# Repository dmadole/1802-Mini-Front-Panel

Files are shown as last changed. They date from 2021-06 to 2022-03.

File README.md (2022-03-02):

# 1802-Mini-Front-Panel
This is the front panel card for the [1802/Mini](https://github.com/dmadole/1802-Mini) system. It supports the following features:

* Supports two, four, or six TIL311 hexadecimal displays
* Left sockets selectable for either LSB or MSB of address
* Toggle switch input to load memory with CDP1802 processor
* Displays and toggle input fully decoded on I/O port 4
* Can separately disable display or toggle I/O ability
* Input switch selectable to EF3 or E4 (or neither)
* Supports LOAD (CDP1802 only), RUN, WAIT, and RESET modes
* In WAIT mode can single-step one machine cycle at a time
* Supports either push button or toggle switch for INPUT
* Stackable to processor card without blocking status LEDs
* Highly annotated silkscreen documents settings and pins

Gerber files for the PCBs and PDF schematics can be found in [Releases](https://github.com/dmadole/1802-Mini-Front-Panel/releases).

BOMS and any applicable errata or other notes can be found in [notes](https://github.com/dmadole/1802-Mini-Front-Panel/tree/main/notes).

For availability of kits and bare PCBs please see http://madole.net/1802/mini/kits

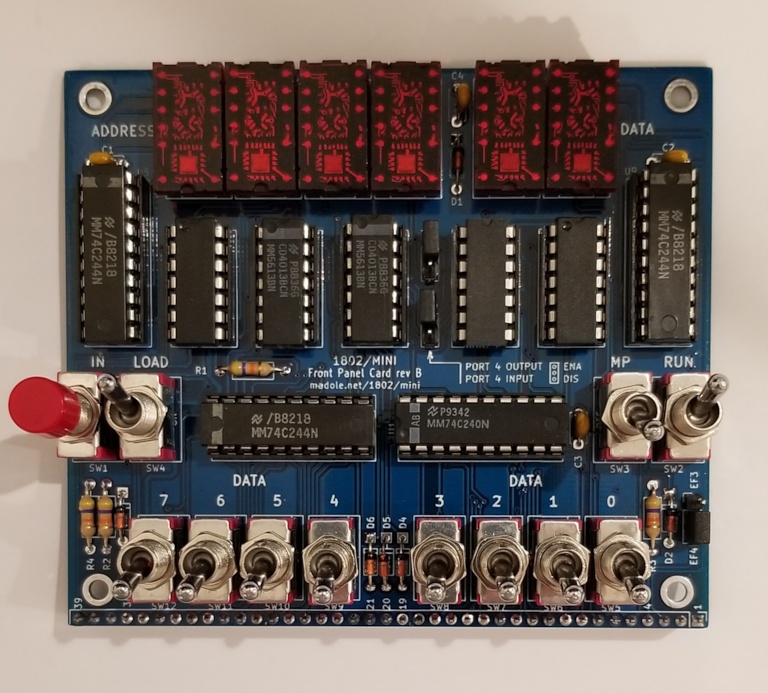
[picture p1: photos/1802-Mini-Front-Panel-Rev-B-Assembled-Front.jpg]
1802/Mini Front Panel Front

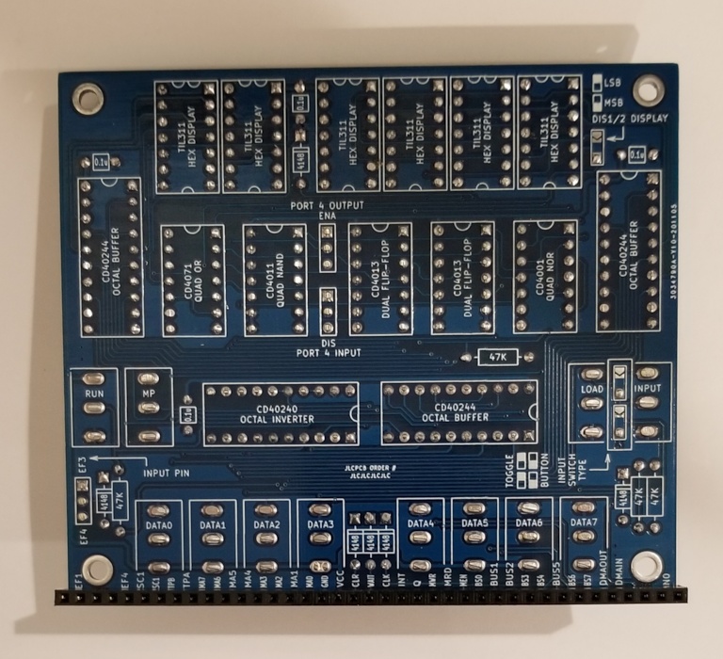
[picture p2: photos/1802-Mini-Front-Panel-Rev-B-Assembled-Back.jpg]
1802/Mini Front Panel Back


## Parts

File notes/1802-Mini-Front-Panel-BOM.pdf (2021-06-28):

Please refer to these notes as applicable for the parts list below:

*A | Rev A and Rev B boards and schematics specified 47K ohms for R1. Recommended value is shown as below, use location reference for placement.
*B | The header pins for configuration jumpers are cut down from longer strips.
*C | The Samtec 39 pin connector, when ordering from Digikey, will always show zero stock because they are made-to-order. They will ship same or next day though.

### FRONT PANEL

Qty | Description | Manufacturer Manufacturer # | Vendor | Vendor # | Price | Qty | Total

Integrated Circuits
6 | Seven segment hex display | DIS1-6 | TI | TIL311 | eBay | 302740853622 | 5.25 | 6.00 | 31.50
1 | CD40240 (or 74C240 or 74HC240) | U1 | TI | SN74HC240N | Digikey | 296-1580-5-ND | 0.66 | 1.00 | 0.66
3 | CD40244 (or 74C244 or 74HC244) | U6 | TI | SN74HC244N | Digikey | 296-1582-5-ND | 0.61 | 3.00 | 1.83
1 | CD4001 | U2 | TI | CD4001BE | Digikey | 296-2028-ND | 0.66 | 1.00 | 0.66
1 | CD4071 | U3 | TI | CD4071BE | Digikey | 296-2062-ND | 0.66 | 1.00 | 0.66
1 | CD4011 | U4 | TI | CD4011BE | Digikey | 296-2031-ND | 0.66 | 1.00 | 0.66
2 | CD4013 | U7-8 | TI | CD4013BE | Digikey | 296-2033-5-ND | 0.66 | 2.00 | 1.32

Discrete Components
1 | Resistor 1/4 watt 4.7K (*A) | R1 | Stackpole | CF14JT4K70 | Digikey | CF14JT4K70CT-ND | 0.10 | 1.00 | 0.10
3 | Resistor 1/4 watt 47K | R2-4 | Stackpole | CF14JT47K0 | Digikey | CF14JT47K0CT-ND | 0.10 | 3.00 | 0.30
6 | Diode 1N4148 | D1-6 | ON Semi | 1N4148 | Digikey | 1N4148FS-ND | 0.10 | 6.00 | 0.60
4 | Ceramic capacitor 0.1uF radial 0.2" | CC1-4 | Valuepro | SR215C104KAA | Jameco | 544921 | 0.19 | 4.00 | 0.76

Switches
11 | SPDT toggle switch 0.185" spacing | SW2-12 | Valuepro | T101T1B1A1 | Jameco | 2135857 | 1.95 | 11.00 | 21.45
1 | SPDT push button 0.185" spacing | SW1 | Valuepro | A101-RD | Jameco | 28063 | 3.29 | 1.00 | 3.29

Interconnects
3 | Straight header 3 pins 0.1" (*B) | | Sullins | PREC040SAAN-RC | Digikey | S1012EC-40-ND | 0.51 | 0.23 | 0.11
3 | Jumper shunts 0.1" | | Sullins | STC02SYAN | Digikey | S9000-ND | 0.10 | 3.00 | 0.30
1 | Socket 39 pin 0.1" short tail (*C) | | Samtec | SSQ-139-01-T-S | Digikey | SAM1184-39-ND | 4.12 | 1.00 | 4.12

Sockets
4 | DIP socket 20 pin 0.3" | | On Shore | ED20DT | Digikey | ED3054-5-ND | 0.26 | 4.00 | 1.04
11 | DIP socket 14 pin 0.3" | | On Shore | ED14DT | Digikey | ED3045-5-ND | 0.19 | 11.00 | 2.09

Mechanical
4 | 0.5 inch standoff spacer | | RAF | 4505-440-AL-7 | Jameco | 393474 | 0.49 | 4.00 | 1.96
1 | Circuit Board | | Madole | | JLCPCB | | 1.95 | 1.00 | 1.95
| | | | | | | Total | | 75.36

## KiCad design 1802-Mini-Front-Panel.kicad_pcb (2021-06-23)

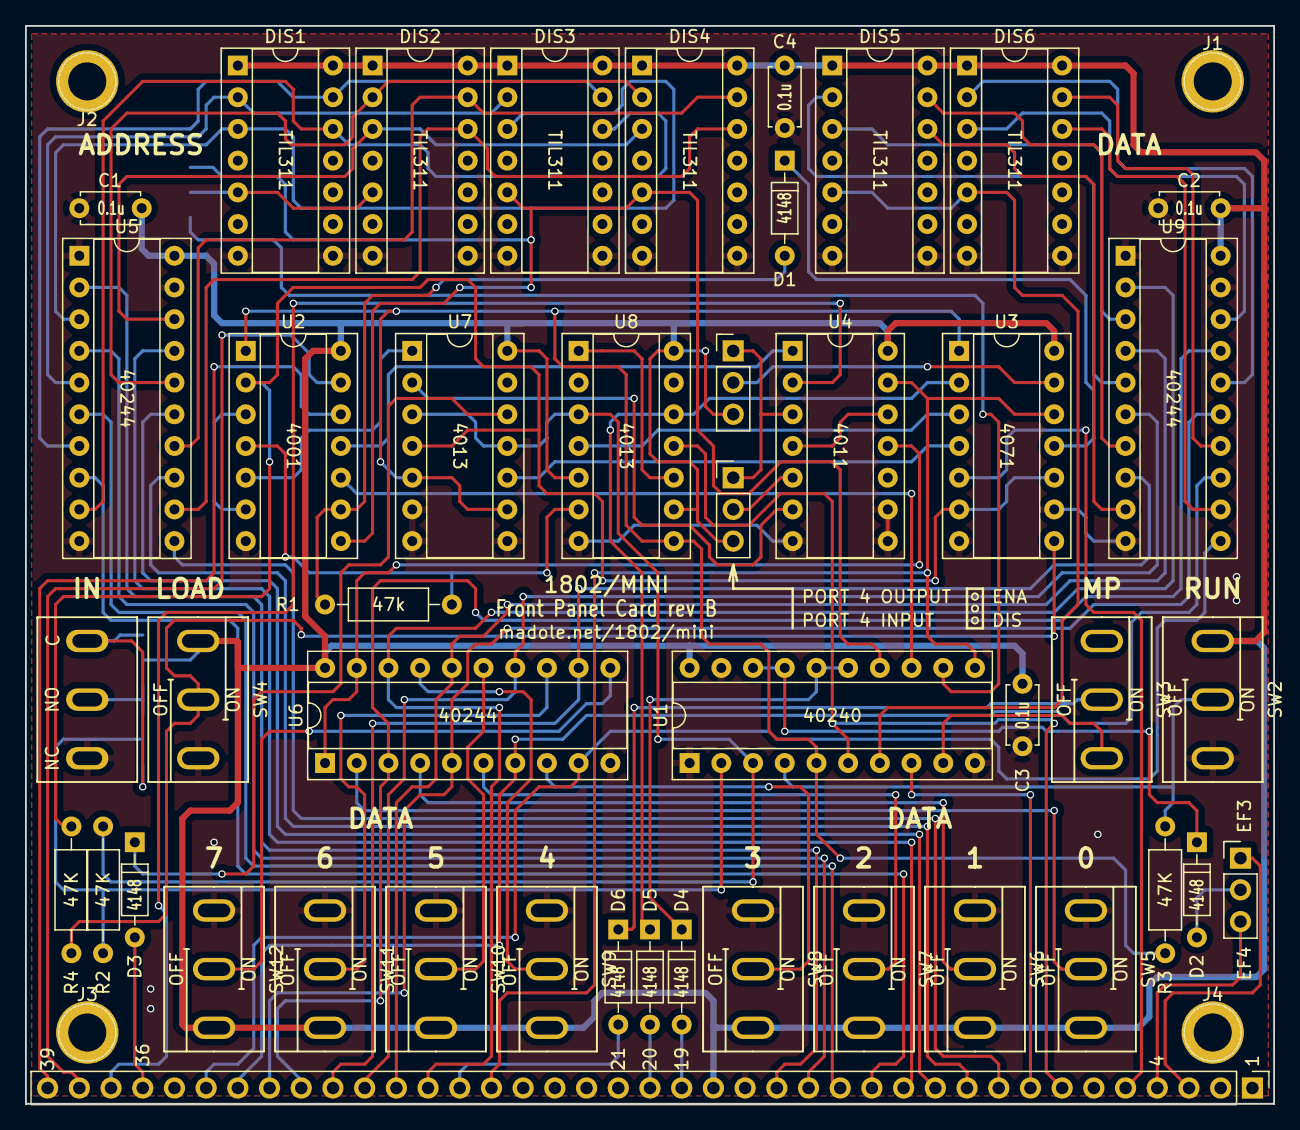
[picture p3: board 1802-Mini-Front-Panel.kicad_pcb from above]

Board: 2 copper layers, 100.0 x 86.4 mm, 52 parts (0 on the bottom side), 90 nets.

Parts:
C1, C2, C3, C4: 0.1u; C_Disc_D4.7mm_W2.5mm_P5.00mm
D1, D2, D3, D4, D5, D6: 1N4148; D_DO-35_SOD27_P7.62mm_Horizontal
DIS1, DIS2, DIS3, DIS4, DIS5, DIS6: TIL311; DIP-14_W7.62mm_Socket
J1, J2, J3, J4: Mount; 1pin
J5: Expansion; Pin_Header_Straight_1x39_Pitch2.54mm
JP1: Button_Toggle_2; SolderJumper-3_P2.0mm_Open_TrianglePad1.0x1.5mm_NumberLabels
JP2: Button_Toggle_1; SolderJumper-3_P2.0mm_Open_TrianglePad1.0x1.5mm_NumberLabels
JP3: IN_EF; Pin_Header_Straight_1x03_Pitch2.54mm
JP4: MA_HI_LO; SolderJumper-3_P2.0mm_Open_TrianglePad1.0x1.5mm_NumberLabels
JP5: OUTPUT; Pin_Header_Straight_1x03_Pitch2.54mm
JP6: INPUT; Pin_Header_Straight_1x03_Pitch2.54mm
R1, R2, R3, R4: 47k; R_Axial_DIN0207_L6.3mm_D2.5mm_P10.16mm_Horizontal
SW1: IN; SPDT_PUSH
SW2: RUN; SPDT_SWITCH
SW3: MP; SPDT_SWITCH
SW4: LOAD; SPDT_SWITCH
SW5: IN0; SPDT_SWITCH
SW6: IN1; SPDT_SWITCH
SW7: IN2; SPDT_SWITCH
SW8: IN3; SPDT_SWITCH
SW9: IN4; SPDT_SWITCH
SW10: IN5; SPDT_SWITCH
SW11: IN6; SPDT_SWITCH
SW12: IN7; SPDT_SWITCH
U1: 40240; DIP-20_W7.62mm_Socket
U2: 4001; DIP-14_W7.62mm_Socket
U3: 4071; DIP-14_W7.62mm_Socket
U4: 4011; DIP-14_W7.62mm_Socket
U5, U6, U9: CD40244; DIP-20_W7.62mm_Socket
U7, U8: 4013; DIP-14_W7.62mm_Socket

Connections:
/BUS0: J5.27, U6.18, U9.2
/BUS1: J5.28, U6.16, U9.4
/BUS2: J5.29, U6.14, U9.6
/BUS3: J5.30, U6.12, U9.8
/BUS4: J5.31, U6.3, U9.17
/BUS5: J5.32, U6.5, U9.15
/BUS6: J5.33, U6.7, U9.13
/BUS7: J5.34, U6.9, U9.11
/MA0: J5.16, U5.2
/MA1: J5.15, U5.4
/MA2: J5.14, U5.6
/MA3: J5.13, U5.8
/MA4: J5.12, U5.17
/MA5: J5.11, U5.15
/MA6: J5.10, U5.13
/MA7: J5.9, U5.11
DMA_IN: D3.2, J5.36
EF3: J5.3, JP3.1
EF4: J5.4, JP3.3
GND: C1.2, C2.2, C3.2, C4.2, DIS1.7, DIS1.8, DIS2.7, DIS2.8, DIS3.7, DIS3.8, DIS4.7, DIS4.8, DIS5.7, DIS5.8, DIS6.7, DIS6.8, J5.17, SW1.3, SW2.3, SW4.3, SW5.1, SW6.1, SW7.1, SW8.1, SW9.1, SW10.1, SW11.1, SW12.1, U1.1, U1.10, U1.19, U2.7, U3.7, U3.9, U4.7, U4.8, U4.9, U5.1, U5.10, U5.19, U6.10, U7.6, U7.7, U7.8, U8.7, U9.1, U9.10, U9.19
MEN: D6.2, J5.26
MRD: J5.25, U1.11, U3.12, U4.13
N0: J5.39, U2.12
N1: J5.38, U2.13
N2: J5.37, U4.2
unnamed: D1.1, U3.11
unnamed: D1.2, R1.2, U2.9
unnamed: D2.1, U1.17, U1.18
unnamed: D2.2, JP3.2
unnamed: D3.1, U7.12
unnamed: D4.1, U1.15, U1.16
unnamed: D5.1, U3.2, U8.12
unnamed: D6.1, SW3.2
unnamed: DIS1.2, DIS3.2, U5.5
unnamed: DIS1.3, DIS3.3, U5.3
unnamed: DIS1.5, DIS2.5, JP4.2
unnamed: DIS1.12, DIS3.12, U5.9
unnamed: DIS1.13, DIS3.13, U5.7
unnamed: DIS2.2, DIS4.2, U5.16
unnamed: DIS2.3, DIS4.3, U5.18
unnamed: DIS2.12, DIS4.12, U5.12
unnamed: DIS2.13, DIS4.13, U5.14
unnamed: DIS5.2, U9.5
unnamed: DIS5.3, U9.3
unnamed: DIS5.5, DIS6.5, U1.7
unnamed: DIS5.12, U9.9
unnamed: DIS5.13, U9.7
unnamed: DIS6.2, U9.16
unnamed: DIS6.3, U9.18
unnamed: DIS6.12, U9.12
unnamed: DIS6.13, U9.14
unnamed: JP1.1, JP2.3, SW1.2
unnamed: JP1.3, JP2.1, SW1.1
unnamed: JP2.2, R2.1, U1.2
unnamed: JP4.1, U1.12
unnamed: JP5.1, JP6.1, U4.3
unnamed: JP5.2, U3.13
unnamed: JP6.2, U4.5
unnamed: R2.2, U1.3, U7.3, U7.11, U8.3
unnamed: R3.1, SW2.2, U1.4
unnamed: R3.2, U1.5, U2.1, U3.1, U7.5, U7.9, U8.8
unnamed: R4.1, SW4.2, U3.8
unnamed: R4.2, U2.2, U3.6, U3.10, U7.4
unnamed: SW3.3, U1.9
unnamed: SW5.2, U6.2
unnamed: SW6.2, U6.4
unnamed: SW7.2, U6.6
unnamed: SW8.2, U6.8
unnamed: SW9.2, U6.17
unnamed: SW10.2, U6.15
unnamed: SW11.2, U6.13
unnamed: SW12.2, U6.11
unnamed: U2.3, U2.6
unnamed: U2.5, U7.1
unnamed: U2.11, U4.1
unnamed: U3.3, U8.4
unnamed: U3.4, U7.10
unnamed: U4.4, U4.12
unnamed: U8.1, U8.10
READ: U4.11, U6.1, U6.19
SC1: J5.5, U3.5
STROBE: U1.13, U2.10
TPA: J5.8, U1.8
TPB: J5.7, U1.6, U8.11
VCC: C1.1, C2.1, C3.1, C4.1, DIS1.1, DIS1.14, DIS2.1, DIS2.14, DIS3.1, DIS3.14, DIS4.1, DIS4.14, DIS5.1, DIS5.14, DIS6.1, DIS6.14, J5.18, JP1.2, JP5.3, JP6.3, SW2.1, SW4.1, SW5.3, SW6.3, SW7.3, SW8.3, SW9.3, SW10.3, SW11.3, SW12.3, U1.20, U2.14, U3.14, U4.14, U5.20, U6.20, U7.14, U8.5, U8.9, U8.14, U9.20
~CLEAR: D4.2, J5.19
~LOAD: U4.6, U7.2
~LOADSTEP: R1.1, U2.4, U8.6
~TPB: DIS3.5, DIS4.5, JP4.3, U1.14, U2.8
~WAIT: D5.2, J5.20

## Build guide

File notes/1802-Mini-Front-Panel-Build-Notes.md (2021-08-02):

# 1802/Mini Front Panel Assembly Notes

Follow usual assembly practices, which I will not document here. I recommend installing the lowest-height components first (resistors, diodes, right-angle connectors), then the next higher (sockets), and so on.

There are a lot of options on this board and it's important to make sure all of them have been selected correctly. Some options are selected with jumpers on the front of the board, and some by bridging solder pads on the back of the board. The board will not work as expected without nearly all options selected one way or the other.

Please see any [applicable errata](https://github.com/dmadole/1802-Mini-Front-Panel/tree/main/notes) before assembling.

## Input Switch Selection
You can use either a push button or a toggle switch (like a momentary one) for the IN switch. There are two solder pads which will need to be closed on the pack of the board depending on which you use.

## Bus Display Count and Selection

If you don't care about the high address displays, you can install only 4 TIL311's, and if you want to keep the board appearance symmetrical, you can install the two address displays in the left-most sockets. There are solder jumpers that will determine if those sockets show the most significant (MSB) or least significant (LSB) of the address. Be sure to close one or the other option even if you use all six displays.

## Single-Step Capability

The front panel is capable of single-stepping CPU cycles. You can do so when already in RUN mode by flipping the LOAD switch on. The IN button will then single-step machine cycles. If you want to step from beginning of program execution instead, from reset, first flip LOAD on first, then RUN, then the IN switch will single-step from address 0000. When single-stepping, the board tries to stop the processor when TPB is high as this is the most useful for hardware troubleshooting, however due to pin latency on the 1802 this does not work at higher clock speeds (above about 2Mhz but depends on the speed of your parts). You can still single-step at higher frequencies but the processor will actually be stopped at the start of the next machine cycle than the address and bus displays show.

## Display and Toggle Port Decoding

Note that unlike most classic Elf designs, the front panel fully decodes IO port 4 rather that responding to all of ports 4-7. This allows ports 5-7 to be used for something else. It is also possible with the jumpers to disable the input and output port functionality if port 4 is needed for something else. Other functions of the front panel still work if this is done.

## Input Switch EF Line

Use EF4 jumper setting for compatibility with typical classic Elf software. The EF3/EF4 jumper can be removed completely if you do not want to use the IN switch for program-controlled input, for example if you need the EF line for another use. The IN switch will still work for other functions (LOAD mode input and single-stepping).

## Lead Trimming

I like to cut all the pins on the back of the board, even the IC sockets, so they are tight with the solder. This can help with clearance on stacked boards, especially with a metal can oscillator. I then also sand over the surface lightly with an emery board to even them a little and remove sharp edges. Of course if you take this latter step, you will need to clean the board well after and be careful since the dust is conductive and probably contains lead, depending on your materials.

## Jumper Settings

The following jumper settings are typical and will enable display and toggle switch input and output on port 4, and INPUT switch status on EF4. If you do not have specific other requirements, these are the recommended starting settings that most software will expect.

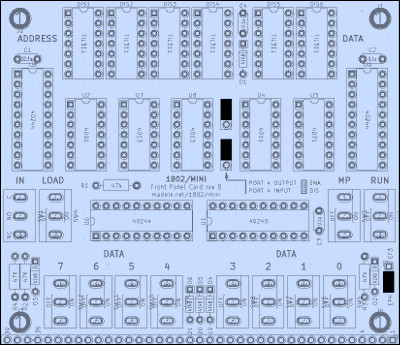
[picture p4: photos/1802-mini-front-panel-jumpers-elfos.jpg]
1802 Mini Front Panel Jumpers


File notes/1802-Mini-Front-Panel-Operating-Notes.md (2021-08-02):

# 1802/Mini Front Panel Operation

The following explains how to operate the various modes on the 1802/Mini front panel. While typical of a "Classic Elf" type computer, there are some differences, especially the availability of the single-step mode, which can be extremely helpful for troubleshooting and learning about the processor.

## Reset
  1. Flip both **LOAD** and **RUN** down

> ### Notes on Reset Mode
> * If the machine is left in run mode with **LOAD** switch down and **RUN** switch up, and the **POWER ON RESET** option on the processor card is enabled, the machine will reset and then enter run mode automatically at power on. You can flip **RUN** down at any time to stop it and move to reset.
> * You should always go to run mode between the load or read modes and the run or single-step modes.

## Load Data to Memory
  1. From reset, flip **LOAD** up and **WP** down _(displays will not change)_
  2. Enter data on **DATA** switches to store into address 0000
  3. Press **INPUT** to store data _(displays will show address 0000 and data stored)_
  4. Enter data on **DATA** switches to store to next address
  5. Press **INPUT** to store data _(displays will shown next address and data stored)_
  6. Repeat from step 4 to write as many bytes as desired
  7. To switch to read mode at any time, flip **WP** up and move to step 3 of "Read Data from Memory"

## Read Data from Memory
  1. From reset, flip **LOAD** and **WP** up _(displays will not change)_
  2. Press **INPUT** to display address 0000 _(displays will show address 0000 and data)_
  3. Press **INPUT** to display next address _(displays will show next address and data)_
  4. Repeat from step 3 to read as many bytes as desired
  5. To switch to load mode at any time, flip **WP** down and move to step 4 of "Load Data to Memory"

> ### Notes on Read and Load Modes
> *  You can freely switch back and forth between write and read mode by changing the **WP** switch as per the last step of either process. This allows editing of single bytes without re-entering all data.
> *  The load and read modes require an 1802 processor, they will not operate with an 1804, 1805, or 1806 processor installed. This is a limitation of those processors.
> *  If the **HI MEM BOOT** option is enabled on the processor card, either load or read mode will access memory starting from address 8000 instead of 0000, although the displays will still show addresses starting from 0000.
> *  If an EEPROM is installed and jumpered for write-enable, it is possible to write to the EEPROM in load mode. Be careful of this as in a usual configuration to boot from ROM this means you can easily overwrite the EEPROM, however it can be very helpful to change a jump vector at the start of the ROM.
> *  You should return to reset following load or read modes before switching to run mode.

## Run
  1. From reset, flip **RUN** up
  2. Program will run from 0000
  3. To pause processor and single-step from current location, flip **LOAD** up (displays show address and data busses)
  4. Each press of **INPUT** will step one machine cycle (displays show address and data busses)
  5. To un-pause processor and resume running at full speed, flip **LOAD** down

## Single Step
  1. From reset, flip **LOAD** up _(displays will not change)_
  2. Flip **RUN** up _(displays will change, but not meaningful)_
  3. Each press of **INPUT** will step one machine cycle (displays show address and data busses)
  4. Repeat step 3 for as as many machine cycles as desired
  5. Flip **LOAD** down to go directly to run from current location and execute at full speed
  6. You can pause and re-enter single step mode at any time by flipping **LOAD** up

> ### Notes on Run and Single Step Modes
> * You can freely move back and forth between run and single-step modes by flipping the **LOAD** switch up to pause and single-step, or down to run.
> * At higher clock speeds, displays in single-step mode may become out of sync with state LEDs on processor card, with the state LEDs reflecting the next processor cycle after what the data displays reflect. This is due to internal processor propagation delays. The speed at which this happens is dependent on the particular processor characteristics. Most processors will stay in sync on this point to at least 2 Mhz.
> * At even higher clock speeds, the high byte of the address displays will become out of sync as well, and will reflect the next processor cycle after what the low address byte and data displays reflect. As with the prior note, this is dependent on the individual processor. Most processors will stay in sync on this point to at least 4 Mhz.
> * You should return to reset following run before switching to load mode.

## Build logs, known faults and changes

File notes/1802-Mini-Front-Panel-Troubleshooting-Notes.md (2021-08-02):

# 1802/Mini Front Panel Troubleshooting Notes

If you are having trouble with the front panel, here are some things to check:

## General
* Check all soldering for quality connections and make sure no adjacent pins have solder bridges.
* Make sure all option settings, either jumpers or solder pads, have been checked and set appropriately.
* Check that all integrated circuits are inserted properly and that there are no bent pins.
* Make sure all diodes are installed with correct polarity, the band should be to the "up" direction towards the displays and away from the bus connector.
* Make sure there is enough clearance to the board under the front panel, especially around the oscillator on the processor card. It is recommend to trim all leads on the back of the card to help avoid shorts to the card below.

## Load Mode and/or Input Switch not Working
* Make sure that the solder pads to select input switch type have been bridged appropriately for the switch type (toggle or push-button) that has been installed.
* If a push-button switch is installed, make sure it is not installed backwards. The common terminal should be away from the expansion bus connector.

## Input Switch Not Recognized by Programs
* Install the **EF3/EF4** jumper (lower-right area on the card) appropriately to the program requirements.

## Displays not Showing Output Data from Programs
* Enable **PORT 4 OUTPUT** jumper between U8 and U4.

## Programs not Inputting from Data Switches
* Enable **PORT 4 INPUT** jumper between U8 and U4.

## Left Two Address Displays not Working Correctly
* Make the proper selection on the **DIS1/2 DISPLAY** solder pads on the back of the board near the highest address display. Select MSB if four address displays are installed or LSB if only two are installed and they are in the left-most positions.

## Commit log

2021-06-23 Add files via upload
    Add BOM
    [1802-Mini-Processor-BOM.xlsx]
2021-06-23 Add BOM
2021-06-27 Added notes and references to BOM
    [1802-Mini-Front-Panel-BOM.xlsx]
2021-06-28 Correct mfr part no of single row header
    [1802-Mini-Front-Panel-BOM.xlsx]
